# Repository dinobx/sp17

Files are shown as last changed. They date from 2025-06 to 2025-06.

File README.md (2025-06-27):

# SP17




**SP17** is a silly little macropad inspired on the optimal solution for packing 17 equal squares into the smallest possible bounding square.

Based on the mathematical packing problem: how can you fit a certain amount of unit squares into the smallest possible rectangle? Read more about the packing problem of x squares on https://www.combinatorics.org/files/Surveys/ds7/ds7v5-2009/ds7-2009.html

## Details

- 17 keys in the optimal packing solution for 17 squares, with options to opt for 2u vertical or horizontal keys in the bottom corners
- MX-compatible, solder only
- Diodeless
- Pro Micro footprint
- Silicone bumper feet cutout on the bottom
- 0° typing angle
- Features the 40%s community Logo where this project originated from
- The PCB has been prototyped by JLCPCB and confirmed to work using the "SP17 PCB.zip" in [production](SP17%20PCB/production)
- The Case was designed and optimized for CNC milling, but is also 3D printable. A CNC'd case has not been prototyped before
- If interest persist a small Groupbuy may be held eventually

## License and Disclaimer

This project is released under the [MIT License](LICENSE). You're free to use, remix, fork, or manufacture this however you want. I am not responsible for any mishaps if you order the PCB or case as-is, however I am confident that there are no issues with this simple design.

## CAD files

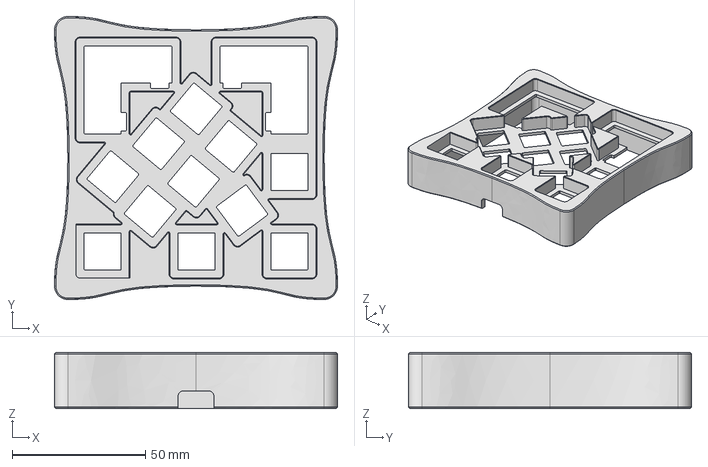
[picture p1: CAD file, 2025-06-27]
SP17 MonoCase.stp
106.0 x 106.0 x 21.0 mm

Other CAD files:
SP17 MonoCase.stl

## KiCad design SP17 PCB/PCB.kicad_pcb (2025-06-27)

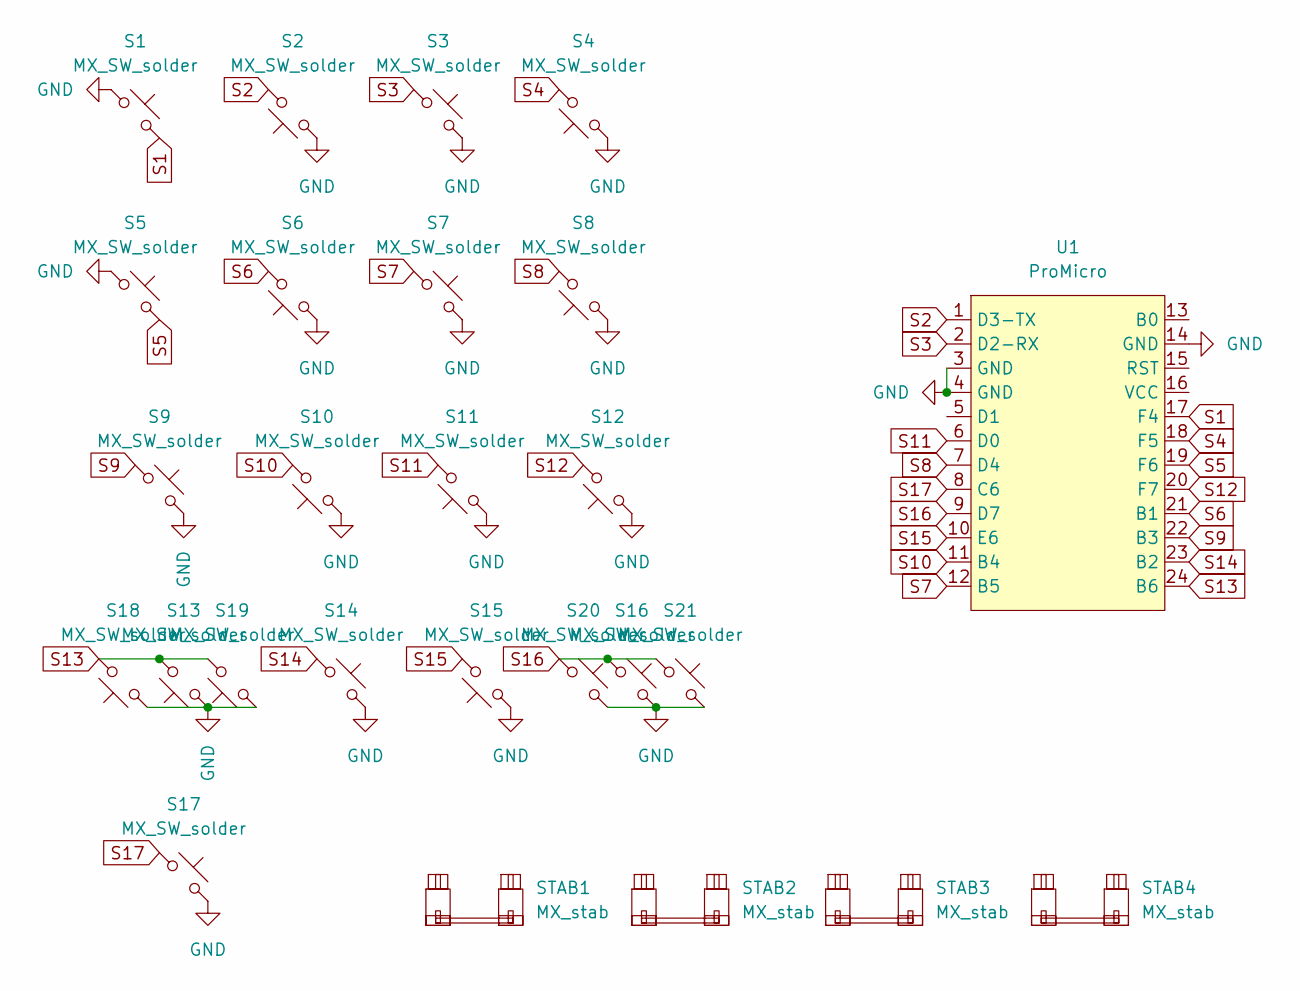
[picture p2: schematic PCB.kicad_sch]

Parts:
S1, S2, S3, S4, S5, S6, S7, S8, S9, S10, S11, S12, S13, S14, S15, S16, S17, S18, S19, S20, S21: MX_SW_solder; SW_MX_1u
STAB1, STAB2, STAB3, STAB4: MX_stab; STAB_MX_2u
U1: ProMicro; ProMicro_USBup

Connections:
GND: S1.1, S2.1, S3.2, S4.1, S5.1, S6.1, S7.2, S8.1, S9.2, S10.1, S11.1, S12.1, S13.1, S14.2, S15.1, S16.2, S17.2, S18.1, S19.1, S20.2, S21.2, U1.3 (GND), U1.4 (GND), U1.14 (GND)
S1: S1.2, U1.17 (F4)
S2: S2.2, U1.1 (D3-TX)
S3: S3.1, U1.2 (D2-RX)
S4: S4.2, U1.18 (F5)
S5: S5.2, U1.19 (F6)
S6: S6.2, U1.21 (B1)
S7: S7.1, U1.12 (B5)
S8: S8.2, U1.7 (D4)
S9: S9.1, U1.22 (B3)
S10: S10.2, U1.11 (B4)
S11: S11.2, U1.6 (D0)
S12: S12.2, U1.20 (F7)
S13: S13.2, S18.2, S19.2, U1.24 (B6)
S14: S14.1, U1.23 (B2)
S15: S15.2, U1.10 (E6)
S16: S16.1, S20.1, S21.1, U1.9 (D7)
S17: S17.1, U1.8 (C6)

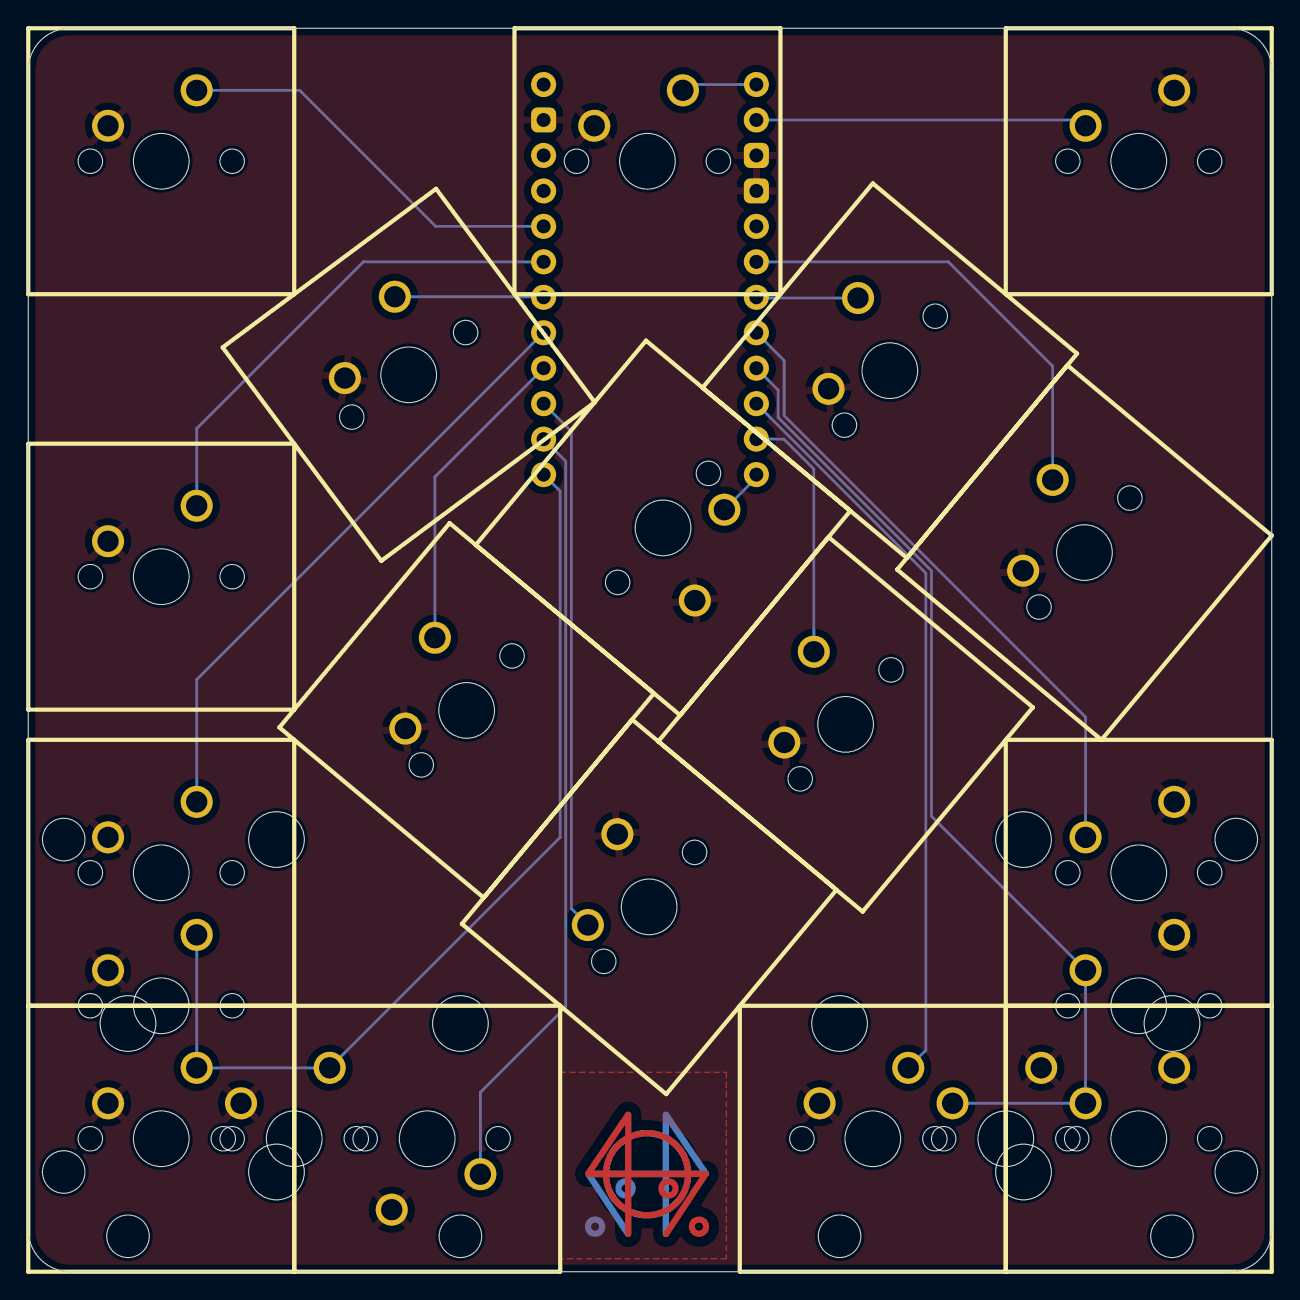
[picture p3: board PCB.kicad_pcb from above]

Board: 2 copper layers, 89.1 x 89.1 mm, 26 parts (1 on the bottom side), 18 nets.

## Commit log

2025-06-27 added SP17 MonoCase.step file
    [SP17 MonoCase.stp]
2025-06-27 added KiCad PCB
    [PCB.kicad_pcb, PCB.kicad_sch]
2025-06-27 added production/PCB.zip
2025-06-27 replaced case file, added stl
    [SP17 MonoCase.stl, SP17 MonoCase.stp]
